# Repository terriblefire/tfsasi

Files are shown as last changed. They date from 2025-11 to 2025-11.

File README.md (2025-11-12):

# TFSASI - SASI to SCSI Adapter




A 3-way universal adapter board for connecting SASI 20-pin, SASI 26-pin, or SCSI 50-pin devices.

> **⚠️ WARNING: This board has not yet been tested. Use at your own risk.**

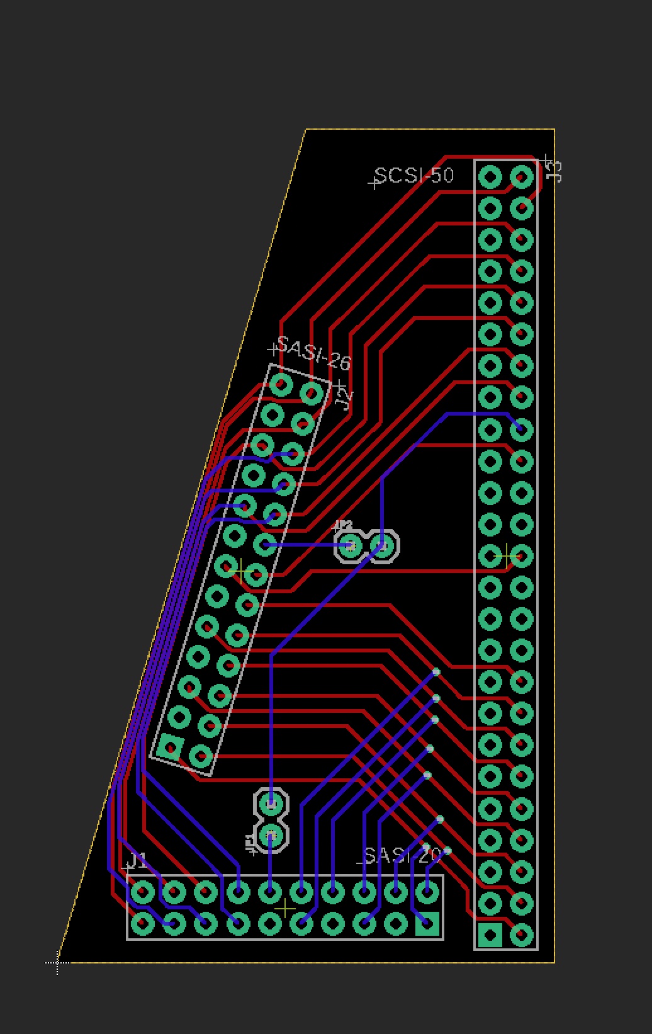
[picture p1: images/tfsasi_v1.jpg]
TFSASI Adapter Board


## Overview

This adapter allows you to connect:
- SASI 20-pin devices to SCSI 50-pin controllers
- SASI 26-pin devices to SCSI 50-pin controllers
- Mix and match between different SASI and SCSI interfaces

## Features

- **3-way adapter**: SASI 20-pin, SASI 26-pin, and SCSI 50-pin connectors
- **4-layer PCB design** for improved signal integrity
- **All signals properly mapped** between connectors
- **LED header connections provided** - Separate headers are included for HDD activity LED signals (SASI-20 pin 12, SASI-26 pin 16) to allow for custom LED driver circuits
- **Mirrored connector footprints** for proper cable orientation
- **Full SCSI-1 compatibility** with parity and attention signals (on 26-pin)

## Connectors

### SASI 20-Pin (J1)
- 2x10 pin header (0.1" pitch)
- Basic SASI interface with data and control signals
- No parity or attention signals
- Pin 12 (LED) is not connected

### SASI 26-Pin (J2)
- 2x13 pin header (0.1" pitch)
- Full SCSI-compatible with parity and attention
- Includes TERMPWR (+5V for termination)
- Pin 16 (LED) is not connected

### SCSI 50-Pin (J3)
- 2x25 pin header (0.1" pitch)
- Standard SCSI-1 interface
- Pin 18 (DBP/parity) connects from SASI 26-pin
- Pin 32 (ATN) connects from SASI 26-pin only

## Documentation

- [PINOUTS.md](PINOUTS.md) - Complete pinout documentation for all connectors
- [LED_SPECIFICATIONS.md](LED_SPECIFICATIONS.md) - Information about LED signal characteristics

## PCB Files

The Eagle schematic and board files are in the `eagle/` directory:
- `tfsasi.sch` - Complete schematic
- `tfsasi.brd` - PCB layout (to be created)

**Note:** The board is configured as a 4-layer PCB with one layer missing. This is intentional for the design requirements.

## Building Gerbers

### Using Make (with Docker)

```bash
cd eagle
make gerbers    # Generate Gerbers and create ZIP
make pdf        # Generate PDF schematic
make clean      # Clean generated files
```

Requires Docker with the `terriblefire78/eagle:v1` image.

### Automated Builds

GitHub Actions automatically generate:
- **Gerber files** on every push to main
- **PDF schematics** on every push to main
- **Release artifacts** when you create a version tag

## Manufacturing

The board is designed for JLCPCB 4-layer manufacturing:
- Standard 1.6mm thickness
- ENIG or HASL finish recommended
- 0.1" (2.54mm) through-hole connectors

## Signal Mapping

All data lines (DB0-DB7) and control signals (BSY, ACK, RST, MSG, SEL, C/D, REQ, I/O) are connected across all three connectors.

Special signals:
- **DBP (Parity)**: Only on SASI 26-pin and SCSI 50-pin
- **ATN (Attention)**: Only on SASI 26-pin and SCSI 50-pin
- **TERMPWR**: Only on SASI 26-pin and SCSI 50-pin
- **LED**: Separate headers provided for HDD activity LED signals from SASI-20 pin 12 and SASI-26 pin 16 (see [LED_SPECIFICATIONS.md](LED_SPECIFICATIONS.md) for driver circuit information)

## License

This project is licensed under the Creative Commons Attribution-ShareAlike 4.0 International License.

See [LICENSE](LICENSE) for details.

## Author

TerribleFire

## Contributing

Contributions are welcome! Please feel free to submit pull requests or open issues for bugs and feature requests.

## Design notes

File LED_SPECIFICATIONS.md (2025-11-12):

# SASI HDD Activity LED Signal Specifications

## Overview

Unfortunately, specific documentation for SASI LED signal levels is not readily available online. The SASI specification documents from Shugart Associates (late 1970s/early 1980s) are not accessible in readable form.

## Expected Characteristics (Based on Era-Appropriate Standards)

### Voltage Levels

SASI used **TTL/LSTTL logic levels** (5V signaling), so the LED signal was likely:
- **0V to 5V voltage range**
- Standard TTL output characteristics
- VOL (low-level output voltage) ≤ 0.4V
- VOH (high-level output voltage) ≥ 2.4V

### Most Likely Implementation

Based on typical HDD activity LED implementations from the late 1970s/early 1980s:

- **Open collector/open drain output** (active low)
- Signal pulls to ground (0V) when active
- Requires external pull-up resistor (typically to +5V through LED)
- Typical current drive capability: 10-20mA
- Could potentially handle up to 48mA (standard TTL sink current)

### Typical LED Driver Circuit

```
+5V ─┬─ [Current Limiting Resistor: 220-470Ω] ─┬─ LED+ (Anode)
     │                                           │
     │                                         LED
     │                                           │
     └─────────────────────────────────────── LED- (Cathode to Pin 12)
```

**Resistor calculation:**
- For 20mA LED current: R = (5V - LED_Vf) / 0.02A
- Red LED (Vf ~2V): R = (5V - 2V) / 0.02A = 150Ω (use 220Ω standard value)
- Green LED (Vf ~2.2V): R = (5V - 2.2V) / 0.02A = 140Ω (use 220Ω standard value)

### Alternative: Push-Pull Output

Some implementations may use **push-pull output**:
- Active high: +5V when drive is active
- Active low: 0V when drive is idle
- Can source and sink current

## Uncertainties

Without the actual SASI specification or specific drive/controller datasheets, the following cannot be confirmed:

- Exact voltage levels
- Maximum current capacity
- Whether output is open collector or push-pull
- Polarity (active high vs active low)
- Whether current limiting is built into the drive controller

## Verification Methods

If you have access to the actual vintage hardware, you can verify these specifications:

1. **Voltage measurement**: Use a multimeter to measure voltage on pin 12
   - Measure when drive is idle
   - Measure when drive is active (during read/write operations)

2. **Current capacity test**: Connect a test LED with series resistor
   - Start with 470Ω resistor for safety (~10mA)
   - Observe if LED illuminates during drive activity
   - If too dim, reduce resistor value incrementally

3. **Signal characteristics**: Use an oscilloscope to observe
   - Signal voltage levels
   - Active high vs active low polarity
   - Pulse width and frequency during activity

4. **Circuit topology**: Check with multimeter in diode/resistance mode
   - Measure resistance between pin 12 and ground
   - Measure resistance between pin 12 and +5V
   - This can indicate if it's open collector (pull-down only) or push-pull

## SASI Pin Assignments

### SASI 20-Pin
- **Pin 12**: LED / HDD Activity (NOT CONNECTED in current adapter)

### SASI 26-Pin
- **Pin 16**: LED / HDD Activity (NOT CONNECTED in current adapter)

## Recommendations

1. Design LED driver circuit that is compatible with both open collector and push-pull outputs
2. Include current limiting resistor in the adapter circuit (don't rely on drive's internal limiting)
3. Use standard 220-470Ω resistor for 5V operation with typical indicator LEDs
4. Consider using a buffer/driver IC if multiple LEDs need to be driven
5. Verify polarity and drive capability before connecting to final LED circuit

## References

- SCSI-1 electrical specifications (SASI's successor): VOL = 1.7V max at 55mA, VOH = 2.7V min
- TTL standard specifications: VOL ≤ 0.4V, VOH ≥ 2.4V
- SASI was the direct predecessor to SCSI-1 and used similar electrical characteristics

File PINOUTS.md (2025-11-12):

# SASI 20-Pin, SASI 26-Pin, and SCSI 50-Pin Pinouts

## SASI 20-Pin Connector Pinout

**Connector Type**: 2x10 pin header (0.1" / 2.54mm pitch)
**Pin Numbering**:
```
  2  4  6  8 10 12 14 16 18 20
  1  3  5  7  9 11 13 15 17 19
```

### Pin Assignments

| Pin | Signal | Direction | Description |
|-----|---|---|---|
| 1 | -DB0 | I/O | Data bit 0 (LSB) |
| 2 | -DB1 | I/O | Data bit 1 |
| 3 | GND | - | Ground |
| 4 | -DB2 | I/O | Data bit 2 |
| 5 | -DB3 | I/O | Data bit 3 |
| 6 | -DB4 | I/O | Data bit 4 |
| 7 | GND | - | Ground |
| 8 | -DB5 | I/O | Data bit 5 |
| 9 | -DB6 | I/O | Data bit 6 |
| 10  | -DB7 | I/O | Data bit 7 (MSB) |
| 11  | GND | - | Ground |
| 12  | LED | Output | HDD Activity LED (not connected)|
| 13  | -BSY | I/O | Busy |
| 14  | -ACK | I/O | Acknowledge |
| 15  | -RST | I/O | Reset |
| 16  | -MSG | I/O | Message |
| 17  | -SEL | I/O | Select |
| 18  | -C/D | I/O | Control/Data |
| 19  | -REQ | I/O | Request |
| 20  | -I/O | I/O | Input/Output |

**Notes**:
- Pins 3, 7, 11 are Ground
- Pin 12 is HDD Activity LED signal - **NOT CONNECTED** in this adapter (requires separate handling)
- All signals are active-low (indicated by - or / prefix)
- Data bits DB0-DB7 form an 8-bit bidirectional data bus
- All control signals are present on this 20-pin connector

---

## SASI 26-Pin Connector Pinout

**Connector Type**: 26-pin IDC ribbon cable connector (2x13, 0.1" / 2.54mm pitch)
**Pin Numbering**:
```
  2  4  6  8 10 12 14 16 18 20 22 24 26
  1  3  5  7  9 11 13 15 17 19 21 23 25
```

### Pin Assignments

| Pin | Signal | Direction | Description |
|-----|---|---|---|
| 1 | -DB0 | I/O | Data bit 0 (LSB) |
| 2 | -DB1 | I/O | Data bit 1 |
| 3 | GND | - | Ground |
| 4 | -DB2 | I/O | Data bit 2 |
| 5 | -DB3 | I/O | Data bit 3 |
| 6 | -DB4 | I/O | Data bit 4 |
| 7 | GND | - | Ground |
| 8 | -DB5 | I/O | Data bit 5 |
| 9 | -DB6 | I/O | Data bit 6 |
| 10  | -DB7 | I/O | Data bit 7 (MSB) |
| 11  | GND | - | Ground |
| 12  | -DBP | I/O | Data parity bit |
| 13  | TERMPWR | Power | Terminator power (+5V) |
| 14  | -ATN | I/O | Attention |
| 15  | GND | - | Ground |
| 16  | LED | Output | HDD Activity LED (not connected)|
| 17  | -BSY | I/O | Busy |
| 18  | -ACK | I/O | Acknowledge |
| 19  | GND | - | Ground |
| 20  | -RST | I/O | Reset |
| 21  | -MSG | I/O | Message |
| 22  | -SEL | I/O | Select |
| 23  | GND | - | Ground |
| 24  | -C/D | I/O | Control/Data |
| 25  | -REQ | I/O | Request |
| 26  | -I/O | I/O | Input/Output |

**Notes**:
- Pins 3, 7, 11, 15, 19, 23 are Ground (alternating pattern)
- Pin 12 has parity signal (-DBP) which the 20-pin SASI lacks
- Pin 13 has TERMPWR (+5V for termination)
- Pin 14 has -ATN (Attention) signal which the 20-pin SASI lacks
- Pin 16 is HDD Activity LED signal - **NOT CONNECTED** in this adapter
- All signals are active-low (indicated by - prefix)
- This connector has all SCSI signals including parity and attention

---

## SCSI-1 50-Pin Connector Pinout

**Connector Type**: 50-pin IDC ribbon cable connector (2x25, 0.1" / 2.54mm pitch)
**Pin Numbering**:
```
  2  4  6  8 10 12 14 16 18 20 22 24 26 28 30 32 34 36 38 40 42 44 46 48 50
  1  3  5  7  9 11 13 15 17 19 21 23 25 27 29 31 33 35 37 39 41 43 45 47 49
```

### Pin Assignments

| Pin | Signal | Direction | Description |
|-----|---|---|---|
| 1 | GND | - | Ground |
| 2 | -DB0 | I/O | Data bit 0 (LSB) |
| 3 | GND | - | Ground |
| 4 | -DB1 | I/O | Data bit 1 |
| 5 | GND | - | Ground |
| 6 | -DB2 | I/O | Data bit 2 |
| 7 | GND | - | Ground |
| 8 | -DB3 | I/O | Data bit 3 |
| 9 | GND | - | Ground |
| 10  | -DB4 | I/O | Data bit 4 |
| 11  | GND | - | Ground |
| 12  | -DB5 | I/O | Data bit 5 |
| 13  | GND | - | Ground |
| 14  | -DB6 | I/O | Data bit 6 |
| 15  | GND | - | Ground |
| 16  | -DB7 | I/O | Data bit 7 (MSB) |
| 17  | GND | - | Ground |
| 18  | -DBP | I/O | Data parity (separate connector)|
| 19  | GND | - | Ground |
| 20  | GND | - | Ground |
| 21  | GND | - | Ground |
| 22  | GND | - | Ground |
| 23  | GND | - | Ground |
| 24  | GND | - | Ground |
| 25  | Open | - | Not connected / Reserved |
| 26  | TERMPWR | Power | Terminator power (+5V) |
| 27  | Open | - | Not connected / Reserved |
| 28  | GND | - | Ground |
| 29  | GND | - | Ground |
| 30  | GND | - | Ground |
| 31  | GND | - | Ground |
| 32  | -ATN | Input | Attention (not connected) |
| 33  | GND | - | Ground |
| 34  | GND | - | Ground |
| 35  | GND | - | Ground |
| 36  | -BSY | I/O | Busy |
| 37  | GND | - | Ground |
| 38  | -ACK | I/O | Acknowledge |
| 39  | GND | - | Ground |
| 40  | -RST | I/O | Reset |
| 41  | GND | - | Ground |
| 42  | -MSG | I/O | Message |
| 43  | GND | - | Ground |
| 44  | -SEL | I/O | Select |
| 45  | GND | - | Ground |
| 46  | -C/D | I/O | Control/Data |
| 47  | GND | - | Ground |
| 48  | -REQ | I/O | Request |
| 49  | GND | - | Ground |
| 50  | -I/O | I/O | Input/Output |

**Notes**:
- All odd-numbered pins are Ground (except pin 25, 27 which are open)
- Even-numbered pins carry signals
- All signals are active-low (indicated by - prefix)
- TERMPWR (pin 26) provides +5V for termination resistors
- Pins 25 and 27 are reserved/not connected
- Pin 18 (-DBP) will be handled via **SEPARATE CONNECTOR** (to be added later)
- Pin 32 (-ATN) is **NOT CONNECTED** in this adapter (SASI does not have ATN signal)

---

## Signal Definitions

### Data Signals (DB0-DB7, DBP)
- **DB0-DB7**: 8-bit bidirectional data bus
- **DBP**: Data parity (odd parity, SCSI only)

### Control Signals
- **-BSY**: Busy - Asserted when bus is in use
- **-SEL**: Select - Used to select a target device
- **-C/D**: Control/Data - Indicates control or data phase
- **-I/O**: Input/Output - Indicates direction of data transfer
- **-MSG**: Message - Indicates message phase
- **-REQ**: Request - Data transfer request from target
- **-ACK**: Acknowledge - Data transfer acknowledge from initiator
- **-ATN**: Attention - Indicates initiator has message for target (SCSI only)
- **-RST**: Reset - Resets all devices on bus

### Power
- **TERMPWR**: Terminator power supply (+5V, typically 500mA-1A)

---

## Important Notes

1. **Signal Polarity**: All signals are active-low (logic 0 = asserted, logic 1 = deasserted)
2. **Ground Pattern**: Alternating signal-ground arrangement for noise immunity
3. **Voltage Levels**: TTL/LSTTL compatible (0V to +5V)
4. **SASI Variations**: This is one common SASI pinout. Different manufacturers may have used different configurations. Always verify with device documentation.
5. **Missing SASI Signals**: The 20-pin SASI connector shown here only includes data and BSY/SEL. Other control signals (REQ, MSG, C/D, I/O, ACK, RST) may be on additional pins or connectors depending on the implementation.

---

## Pinout Verification

Before connecting any hardware, verify pinouts using:
- Original device documentation
- Oscilloscope or logic analyzer
- Continuity testing with multimeter
- Examination of existing cables

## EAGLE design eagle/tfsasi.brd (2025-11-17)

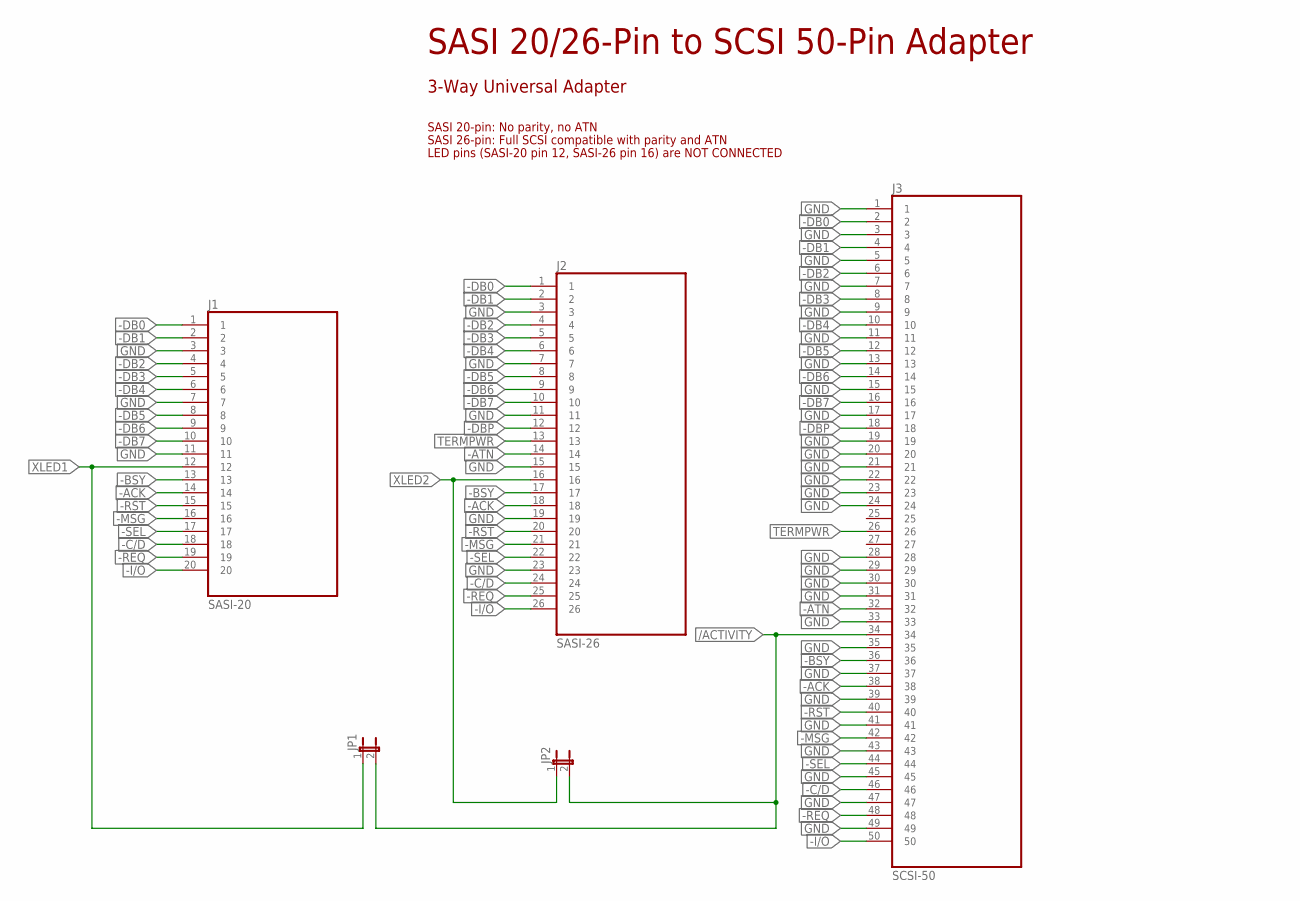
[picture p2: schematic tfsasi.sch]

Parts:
J1: SASI-20; 2X10
J2: SASI-26; 2X13
J3: SCSI-50; 2X25
JP1, JP2: JUMPER-2PTH; 1X02

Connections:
-ACK: J1.14, J2.18, J3.38
-ATN: J2.14, J3.32
-BSY: J1.13, J2.17, J3.36
-C/D: J1.18, J2.24, J3.46
-DB0: J1.1, J2.1, J3.2
-DB1: J1.2, J2.2, J3.4
-DB2: J1.4, J2.4, J3.6
-DB3: J1.5, J2.5, J3.8
-DB4: J1.6, J2.6, J3.10
-DB5: J1.8, J2.8, J3.12
-DB6: J1.9, J2.9, J3.14
-DB7: J1.10, J2.10, J3.16
-DBP: J2.12, J3.18
-I/O: J1.20, J2.26, J3.50
-MSG: J1.16, J2.21, J3.42
-REQ: J1.19, J2.25, J3.48
-RST: J1.15, J2.20, J3.40
-SEL: J1.17, J2.22, J3.44
/ACTIVITY: J3.34, JP1.2, JP2.2
GND: J1.3, J1.7, J1.11, J2.3, J2.7, J2.11, J2.15, J2.19, J2.23, J3.1, J3.3, J3.5, J3.7, J3.9, J3.11, J3.13, J3.15, J3.17, J3.19, J3.20, J3.21, J3.22, J3.23, J3.24, J3.28, J3.29, J3.30, J3.31, J3.33, J3.35, J3.37, J3.39, J3.41, J3.43, J3.45, J3.47, J3.49
TERMPWR: J2.13, J3.26
XLED1: J1.12, JP1.1
XLED2: J2.16, JP2.1

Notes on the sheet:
SASI 20/26-Pin to SCSI 50-Pin Adapter
3-Way Universal Adapter
SASI 20-pin: No parity, no ATN
SASI 26-pin: Full SCSI compatible with parity and ATN
LED pins (SASI-20 pin 12, SASI-26 pin 16) are NOT CONNECTED

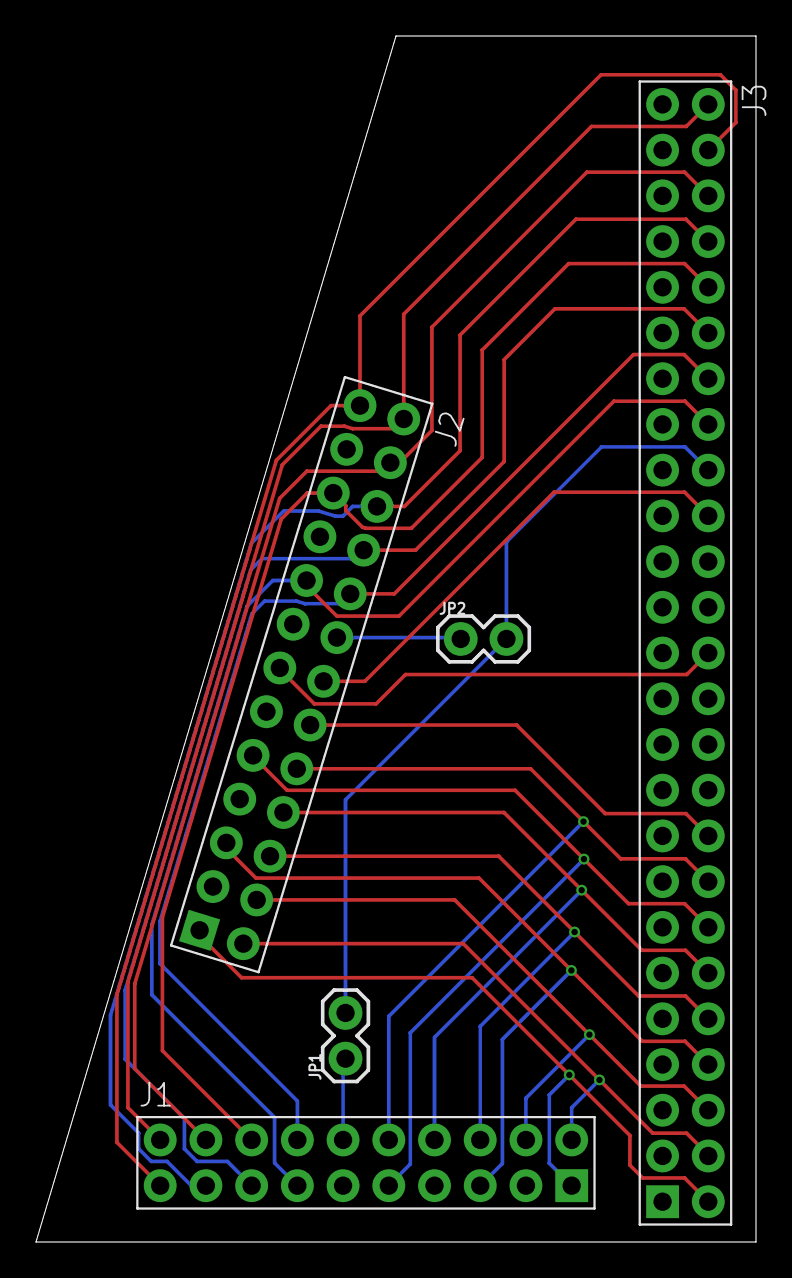
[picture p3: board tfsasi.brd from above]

Board: 4 copper layers, 40.0 x 67.0 mm, 5 parts (0 on the bottom side), 23 nets.

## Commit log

2025-11-12 Initial commit: SASI 20/26-pin to SCSI 50-pin adapter
    - Complete Eagle schematic with mirrored connectors
    - 3-way adapter: SASI 20-pin, SASI 26-pin, and SCSI 50-pin
    - Pinout documentation for all connectors
    - LED signal specifications
    - GitHub workflows for automated Gerber and PDF generation
    - Makefile for local Gerber generation using Docker
    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
    [tfsasi.brd, tfsasi.sch]
2025-11-12 Add board image to README
2025-11-12 Add note about 4-layer board configuration with one layer missing
2025-11-12 Add warning that board has not yet been tested
2025-11-12 Clarify that LED headers are provided for custom LED driver circuits
2025-11-17 Fixed thermal widths
    [tfsasi.brd]

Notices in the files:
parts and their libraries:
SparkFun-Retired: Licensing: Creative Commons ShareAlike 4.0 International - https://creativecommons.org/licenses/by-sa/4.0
